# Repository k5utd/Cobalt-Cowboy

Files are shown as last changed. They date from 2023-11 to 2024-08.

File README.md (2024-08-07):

# Cobalt-Cowboy

A RISC-V-based digital mode radio running OpenRTX Radio Firmware

The goal of this project is to make available a hackable radio development platform for evaluating radio transceivers and experimenting with amateur multi-mode radio technology.

The intended users of this project include licenced Amateur Radio operators and students.

> [!NOTE]
> This repository includes the PCB, Schematic, and associated [KiCAD](https://www.kicad.org/) project files, as well as a parts list and any information necessary to build your own Cobalt Cowboy.

## Background

### OpenRTX Real-Time Operating Systems

This project intends to leverage the growing RF vendor support of Zephyr Project [ZephyrRTOS](https://zephyrproject.org/learn-about/).

The [OpenRTX firmware](https://openrtx.org) is an RTOS-agnostic application built from the ground-up with digital mode radios (DMR) in mind, some of which support the M17 protocol with hardware modification after firmware flashing.

The OpenRTX firmware typically uses the [Miosix](https://miosix.org/) kernel, primarily supporting STM32 targets on the ARM Cortex-M4F architecture, and is being ported to ZephyrRTOS to take advantage of support for more architectures.

### M17 Digital Mode and Codec2

For the purposes of this project, having multiple vocoder options to choose from for digital mode operation is desirable for reducing vendor lockin and avoiding product obsolescence.

The [M17 Project](https://m17project.org/) M17 RF protocol is an open protocol specification that leverages [Codec2](https://en.wikipedia.org/wiki/Codec_2) instead of DVSI [AMBE](https://en.wikipedia.org/wiki/Multi-Band_Excitation). 

Codec2 allows for open implementations as a software-defined vocoding alternative to DVSI vocoding hardware, complimenting the open communication stack of M17.

### Limitations and Alternatives 

The LILYGO [T-TWR Plus](https://www.lilygo.cc/products/t-twr-rev2-1) is a development board for evaluating the `NiceRF SA868` Walkie Talkie and `Quectel L76K` GNSS modules. The T-TWR Plus is as of September 2023 what motivated the OpenRTX team to begin porting OpenRTX to ZephyrRTOS. As of July 2024, rev2.1 now shows promise for experimenting with software-defined digital mode radio on VHF or UHF with improved RF module interfacing.

LILYGO has maintains a [repository](https://github.com/Xinyuan-LilyGO/T-TWR) of example testing firmware and schematics, However, the T-TWR Plus is not necessarily open source hardware, being schematic-available with no manufacturing files. NiceRF does not maintain public factory firmware of the SA868 either, so OpenRTX [sa8x8-fw](https://github.com/OpenRTX/sa8x8-fw) is necessary for use with OpenRTX.

## Getting Started

> [!IMPORTANT]
> This repository is primarily the hardware, the firmware and instructions are to be made available upstream OpenRTX.

### Board Fabrication

The board stackup is intended for OSHPark fabrication services.

The main board features an Espressif `ESP32-C3` and integrates the Texas Instruments `CC1200` Sub-Ghz transceiver. Most components are surface mount, and can get as small as `0602`.

### Firmware 
1. Set up the [Zephyr](https://docs.zephyrproject.org/latest/develop/getting_started/index.html) development environment
2. Set up the [Zephyr-based target toolchain](https://openrtx.org/#/compiling?id=compiling-a-zephyr-based-target) for OpenRTX
3. TODO: Build and compile an OpenRTX image for the `cobalt-cowboy` target

## Contact

To reach out, please join the Discord server.



CO: [Eric Mutton](https://github.com/ericmutton), username `cyndre`.

## License

This project is released under the GNU GPL v3.

See [LICENSE](LICENSE)

## Credits

Our thanks go to the following organizations for their efforts and advice:
* [M17 Project](https://m17project.org/) for their digital radio protocol for data and voice
* [OpenRTX](https://openrtx.org) for their radio firmware for digital mode radios and ham devices

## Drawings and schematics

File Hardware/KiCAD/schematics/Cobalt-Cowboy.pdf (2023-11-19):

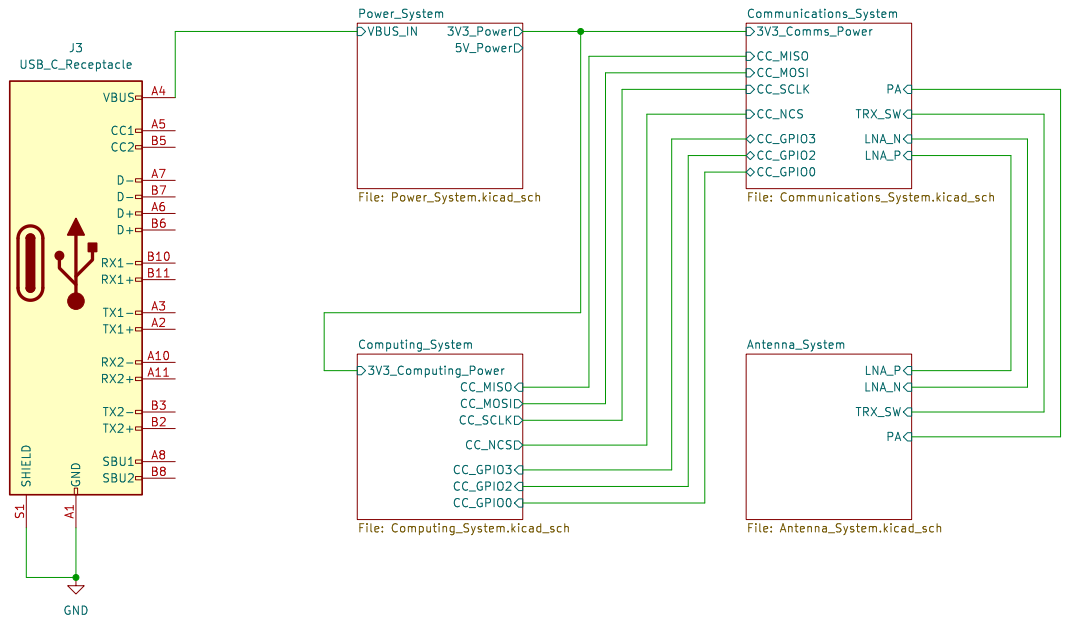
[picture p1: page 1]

Id: 1/6 Title: File: Cobalt-Cowboy.kicad_sch Sheet: /

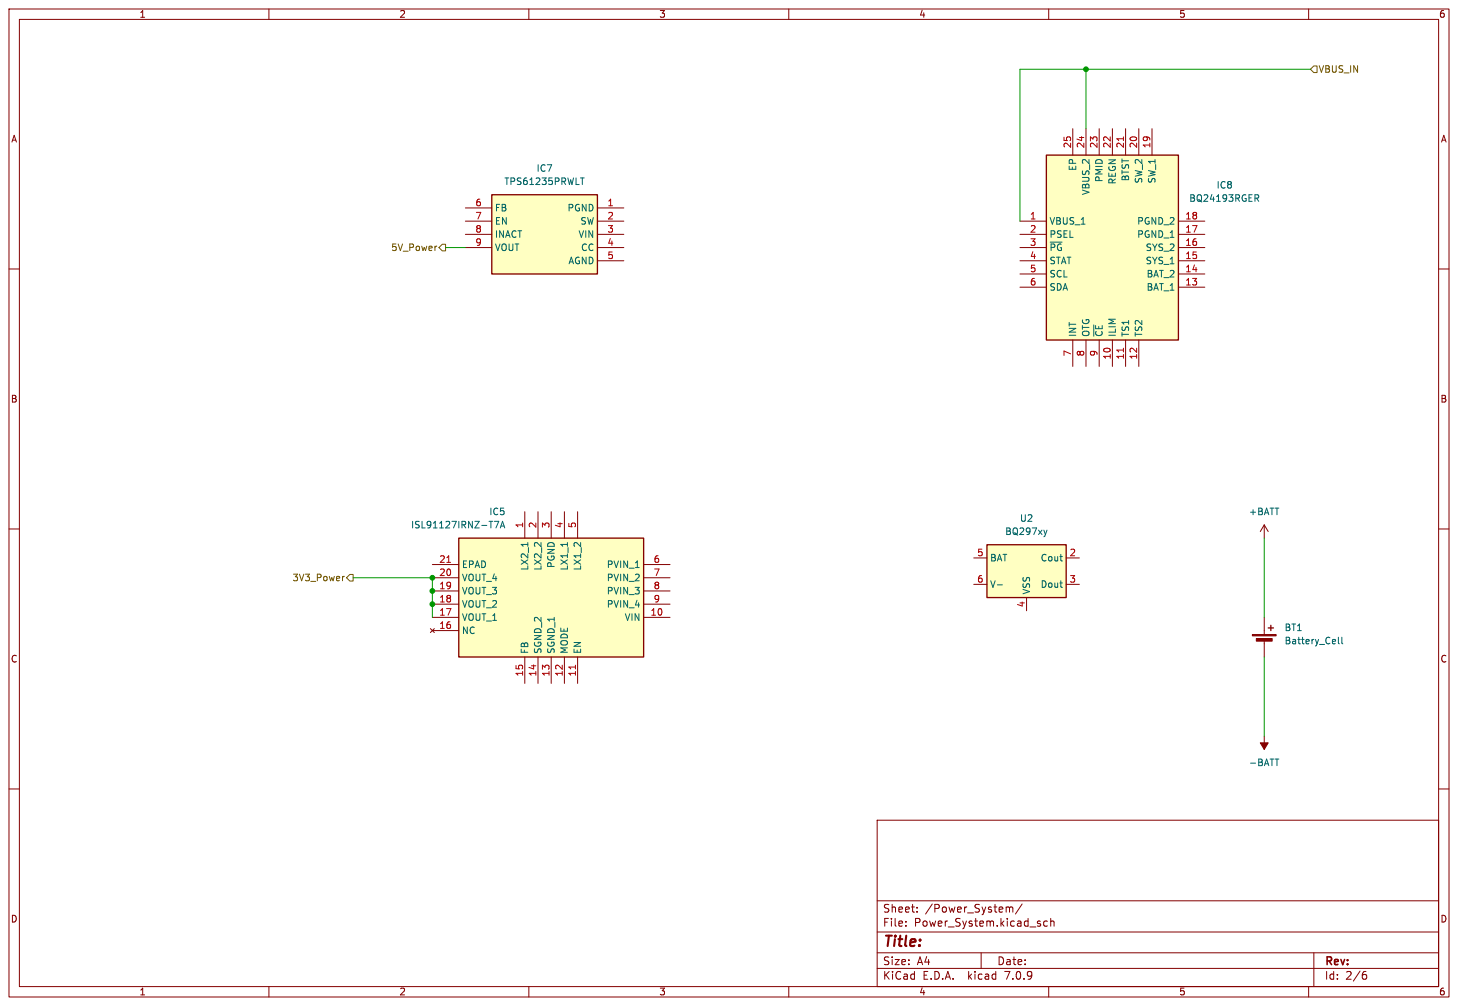
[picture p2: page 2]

1 VIN 10 EN 11 MODE 12 SGND_1 13 SGND_2 14 FB 15 NC 16 VOUT_1 17 VOUT_2 18 VOUT_3 19 LX2_2

Id: 2/6 Title: File: Power_System.kicad_sch Sheet: /Power_System/

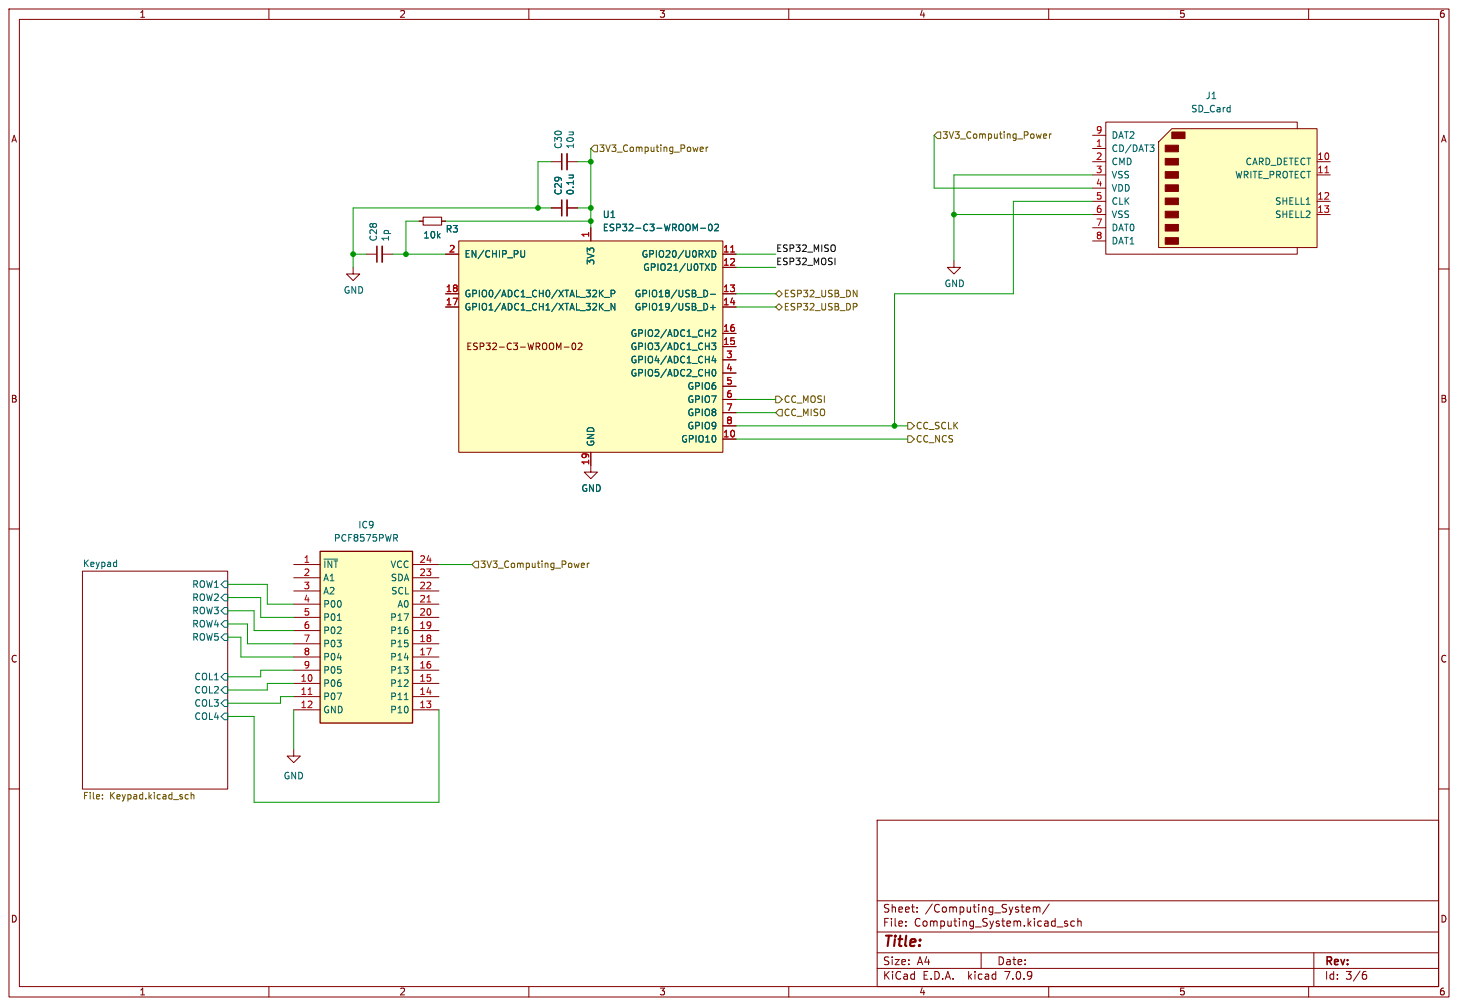
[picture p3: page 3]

1 GPIO10 10 GPIO20/U0RXD 11 GPIO21/U0TXD 12 GPIO18/USB_D- 13 GPIO19/USB_D+ 14 GPIO3/ADC1_CH3 15 GPIO2/ADC1_CH2 16 GPIO1/ADC1_CH1/XTAL_32K_N 17 GPIO0/ADC1_CH0/XTAL_32K_P 18 GND 19 EN/CHIP_PU 2 GPIO4/ADC1_CH4 3 GPIO5/ADC2_CH0 4 GPIO6 5 GPIO7 6 GPIO8 7 GPIO9 8 U1ESP32-C3-WROOM-02 GND GND C30 10u CC_MOSI CC_MISO

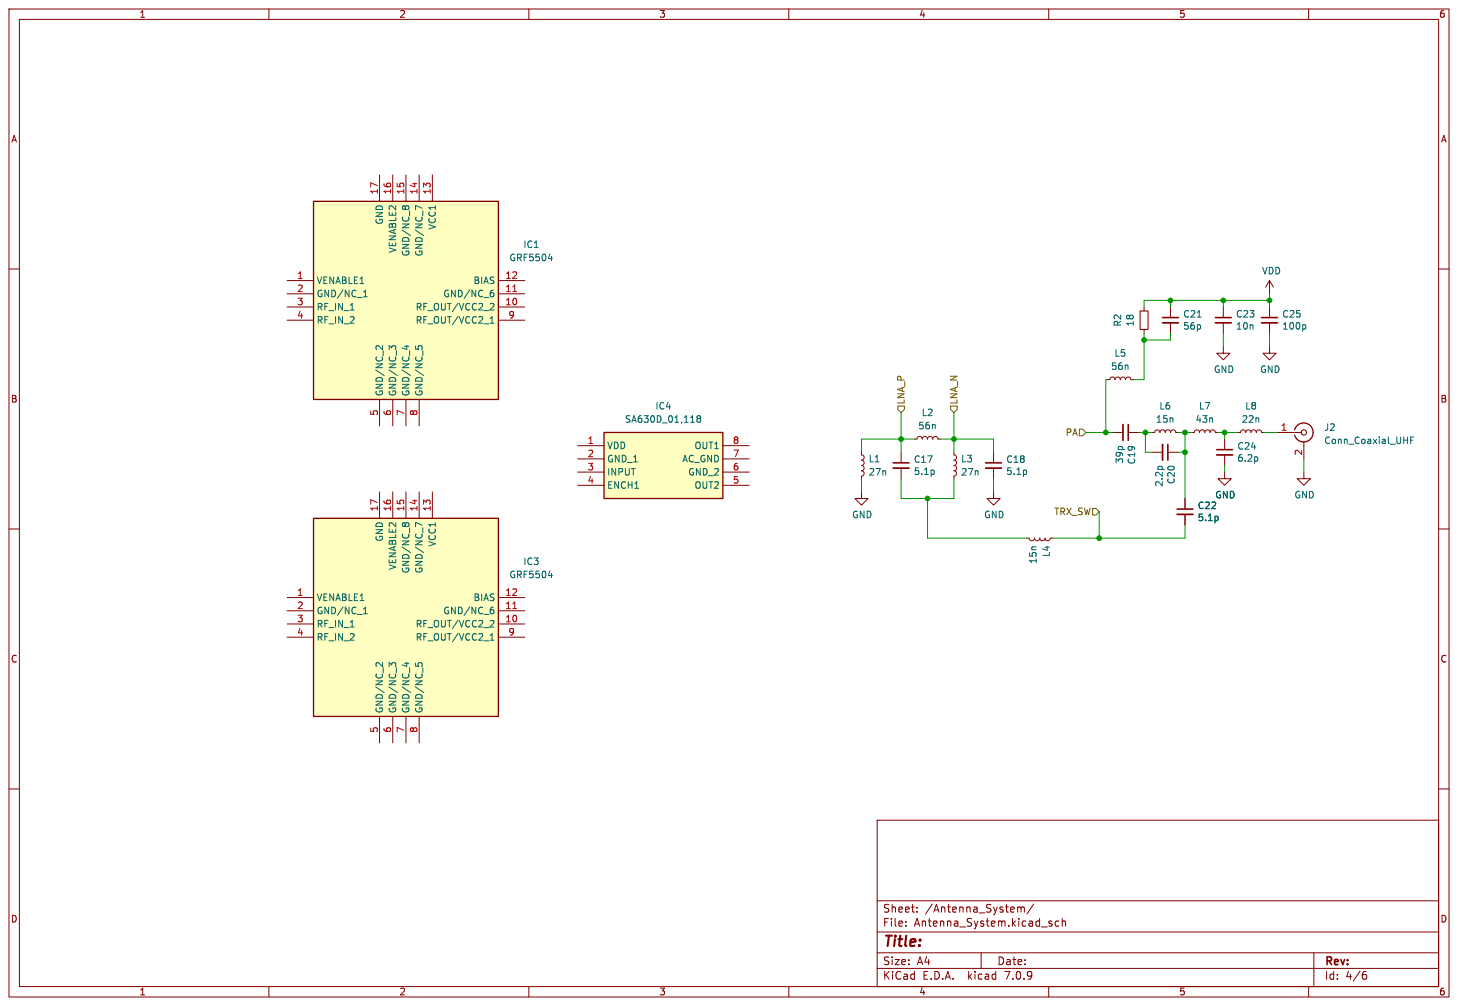
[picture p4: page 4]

Id: 4/6 Title: File: Antenna_System.kicad_sch Sheet: /Antenna_System/

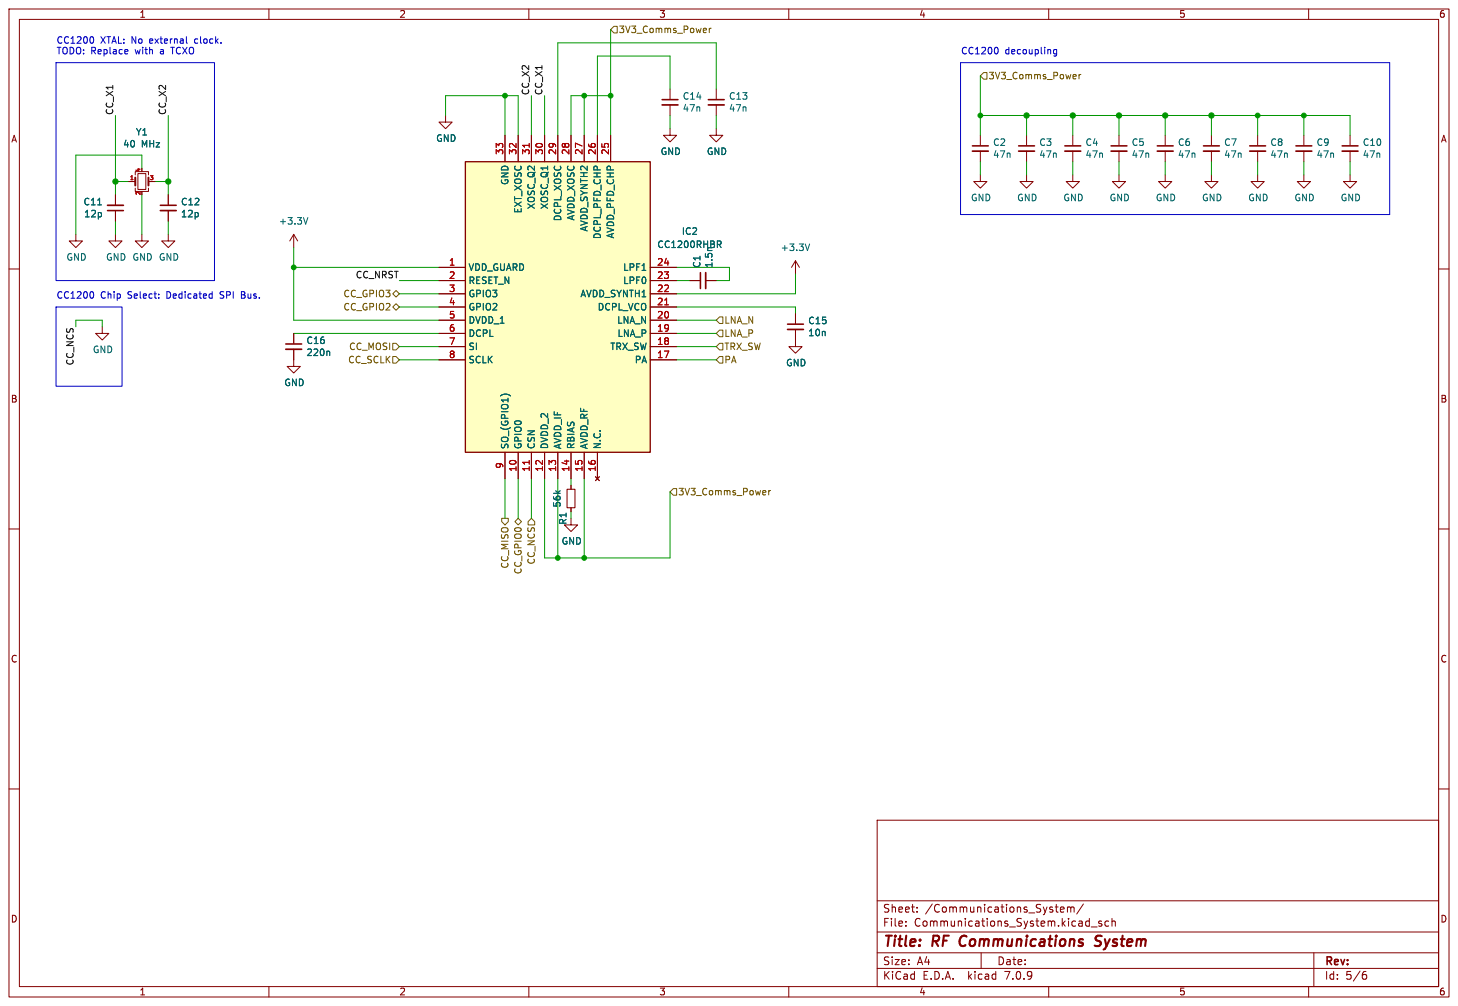
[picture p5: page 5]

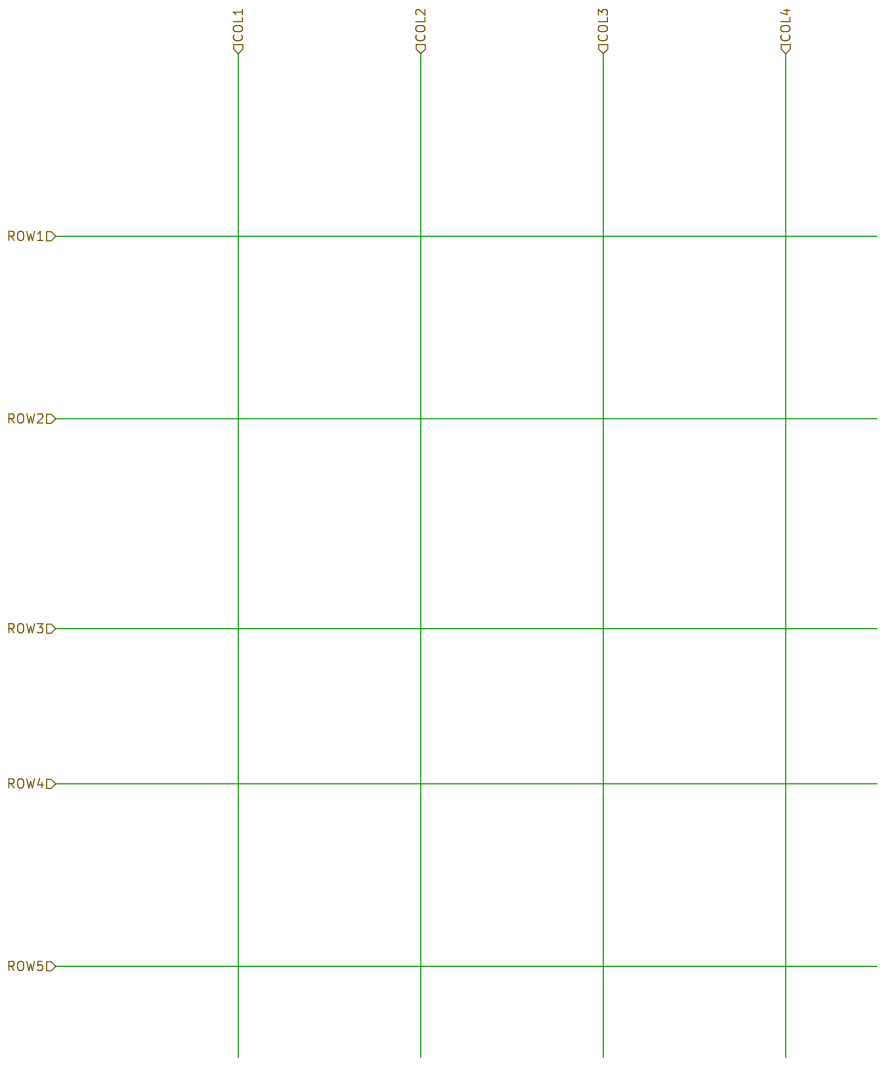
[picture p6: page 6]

Id: 6/6 Title: File: Keypad.kicad_sch Sheet: /Computing_System/Keypad/

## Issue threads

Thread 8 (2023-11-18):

URGENT: Identify I2C bus pins for ESP32 and confirm SPI pins

AbleArcher88, 2023-11-18:
We still haven't actually defined the pins for the I2C bus. This will be very important if we want to integrate most peripherals. Also, we need to double check the SPI bus.

ericmutton, 2023-11-19:
The ESP32-C3 has two kinds of GPIO pins, one type at 20 MHz and another at 80 MHz, according to the datasheet.

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
[C3 Module.png](https://github.com/k5utd/Cobalt-Cowboy/assets/64441308/a8413461-bbc3-401c-8631-d7f1f4cd8d37)

AbleArcher88, 2023-12-11:
I'll leave the assignment of pins to you

ericmutton, 2024-02-09:
Marked done, see https://github.com/zephyrproject-rtos/zephyr/commit/5686368eecf0cf6115c8475e8b7d3c19a32edc07

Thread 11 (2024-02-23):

Draw Schematics for Subsystems

ericmutton, 2024-02-23:
All schematics must be Hierarchical Sheets accessible under [Cobalt-Cowboy.kicad_sch](https://github.com/k5utd/Cobalt-Cowboy/blob/main/Hardware/KiCAD/Cobalt-Cowboy.kicad_sch)

## Communications System
The communications subsystem focuses on the Texas Instruments CC1200RHBR transceiver.
- Decoupling capacitors on all power pins
- See CC1200EM 420- to 470-MHz Reference Design ([SWR122](http://www.ti.com/lit/zip/swrr122))
## Power System
The power system must supply the following VDC levels:
- 3.3 VDC for Communications and Computing subsystems
- 5.0 VDC for Antenna System.
## Computing System
The computing subsystem encompasses both the ESP32-C3-WROOM-02-N4 SoC and its peripherals.
### Display
OpenRTX supports any SH1107-based display, would work OOB with the Mini17 and Module17 implementation and PCB/schematic.
### Keypad
They keypad must include DTMF keys and navigation keys for the OpenRTX user interface.
## Antenna System
Must be suitable for 8W amplification of the Communications subsystem RF power.

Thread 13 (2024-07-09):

Create Testbench for Computer, Communications Subsystems

ericmutton, 2024-07-09:
## Preconditions
The testbench must be able to:
- Be powered over USB 2.0 (5V@500mA) for rapid firmware prototyping.
- Demonstrate MCU module behavior within computer subsystem during daughter board DUT
- Have a 70cm antenna tuned for the K5RWK Multimode Repeater.
  - 443.375 (+5MHz, 110.9) FM + Multi-Mode Digital
Multi-Mode (FM, DMR, D-Star, M17, P25)

## Postconditions
The testbench must enable a DUT for repeater operation.
- Measure RX and TX conditions with the unaltered [TI CC1200 Evaluation Module](https://www.ti.com/tool/CC1200EMK-420-470)
  - Validate [M17 Project CC1200 Experiments](https://wiki.m17project.org/cc1200) and simplify computer subsystem to not require a dedicated MCU for both modem/smartmic functionality and daughter board communications.

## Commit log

2023-10-08 Initialize KiCAD project
    [Cobalt-Cowboy.kicad_pcb, Cobalt-Cowboy.kicad_sch]
2023-10-09 Added Basic Layout, as well as created library file and added symbols
    [Antenna_System.kicad_sch, Cobalt-Cowboy.kicad_sch, Communications_System.kicad_sch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]
2023-10-15 chore: Remove and ignore local KiCAD backups
2023-10-16 fix: Update C3 to reference footprint, symbol
2023-10-16 chore: switch to lowercase file extension
2023-10-16 feat: Connect ESP32 to CC1200
    [Communications_System.kicad_sch, Computing_System.kicad_sch]
2023-10-16 chore: ignore KiCAD cache and table files
2023-10-16 fix: Change some global labels to heirarchical
    [Antenna_System.kicad_sch]
2023-10-21 feat: add models, correct hierarchical patterns
    [Cobalt-Cowboy.kicad_sch, Communications_System.kicad_sch, Computing_System.kicad_sch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]
2023-10-23 added battery to start power systen
    [Cobalt-Cowboy.kicad_sch, Communications_System.kicad_sch, Power_System.kicad_sch]
2023-10-31 added schematics
2023-10-31 Renamed and added the kicad library
    [Antenna_System.kicad_sch, Communications_System.kicad_sch]
2023-11-18 Added a test for commit
    [Power_System.kicad_sch]
2023-11-18 Added components for amplifier, RF switch, 5v Boost, renamed footprints
    [Cobalt-Cowboy.kicad_sch, Communications_System.kicad_sch, Computing_System.kicad_sch]
2023-11-18 feat: corrected Power routing, added TODOs for board, prepared for amps
    [Antenna_System.kicad_sch, Cobalt-Cowboy.kicad_sch, Communications_System.kicad_sch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]
2023-11-18 added keypad
    [Cobalt-Cowboy.kicad_sch, Computing_System.kicad_sch, Keypad.kicad_sch]
2023-11-18 Changed Keypad to better accomidate use of GPIO and removed inc symbols
    [Antenna_System.kicad_sch, Communications_System.kicad_sch, Computing_System.kicad_sch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]
2023-11-19 Added 3.3v converter
    [Communications_System.kicad_sch, Power_System.kicad_sch]
2023-11-19 Added a GND to USBC connector
    [Cobalt-Cowboy.kicad_sch]
